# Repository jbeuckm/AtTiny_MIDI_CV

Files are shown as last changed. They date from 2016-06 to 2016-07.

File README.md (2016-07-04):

# AtTiny85 MIDI-2-CV

Here is a little MIDI interface with a few, inexpensive parts on a single-sided PCB for DIY enthusiasts. 

An ATTINY85 microcontroller ($1.67) implements the SoftwareSerial and MIDI libraries, along with one to control a MCP4822 DAC for pitch and velocity CV outputs. A simple transistor switch enables a full-swing gate output. Pitch Bend messages smoothly change the pitch independent of the gate signal.

### Pitch + CV Normals

The gate jack is normalled to the gate bus of the Eurorack connector. The pitch jack is normalled to the CV bus of the Eurorack connector.

### Set MIDI Channel

A six-byte System Exclusive message can be used to change the channel of the interface.

`F0` sysex start

`77 00 00` manufacturer + model + device

`03` channel (0 for omni) 

`F7` end of message

### Tuning

A trim pot is used to tune the pitch output for 1V/octave. At powerup, before any MIDI mesages are received, the pitch CV should be set to 8.0V.

### Assembly Notes

The MCP4822 library has been modified to sendSPIClock() using `delayMicroseconds()` instead of `delay()` so that pitch bend is smooth.

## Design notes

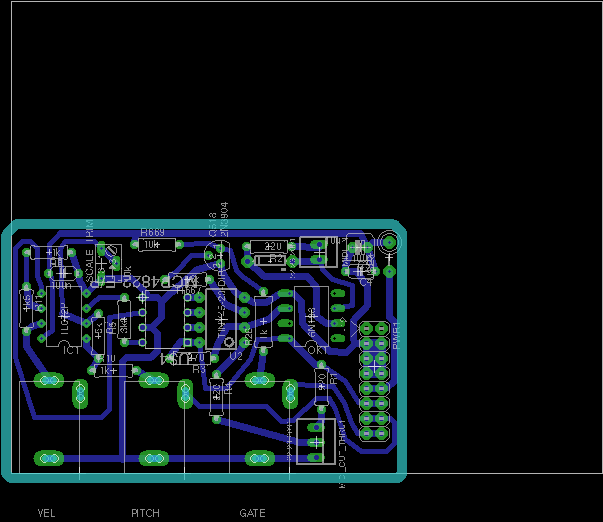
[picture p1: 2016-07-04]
eagle/attiny_midi_cv.png

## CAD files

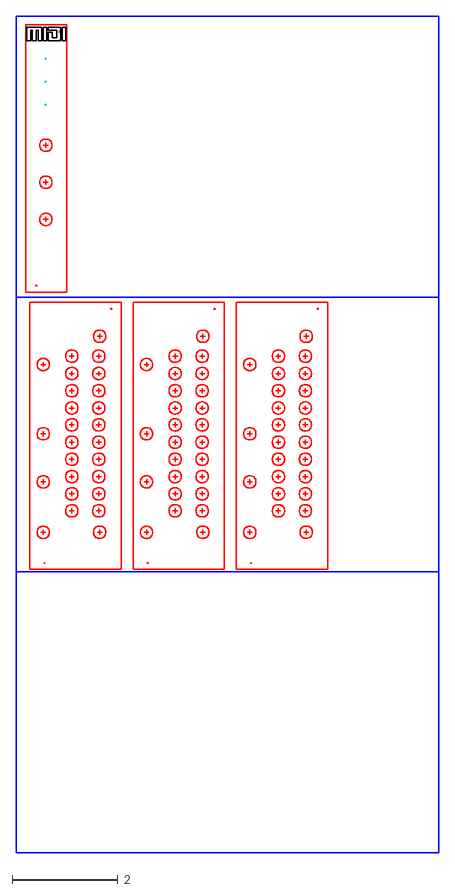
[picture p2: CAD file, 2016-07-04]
panel/attiny_midi_cv_panel.dxf
8.00 x 15.8

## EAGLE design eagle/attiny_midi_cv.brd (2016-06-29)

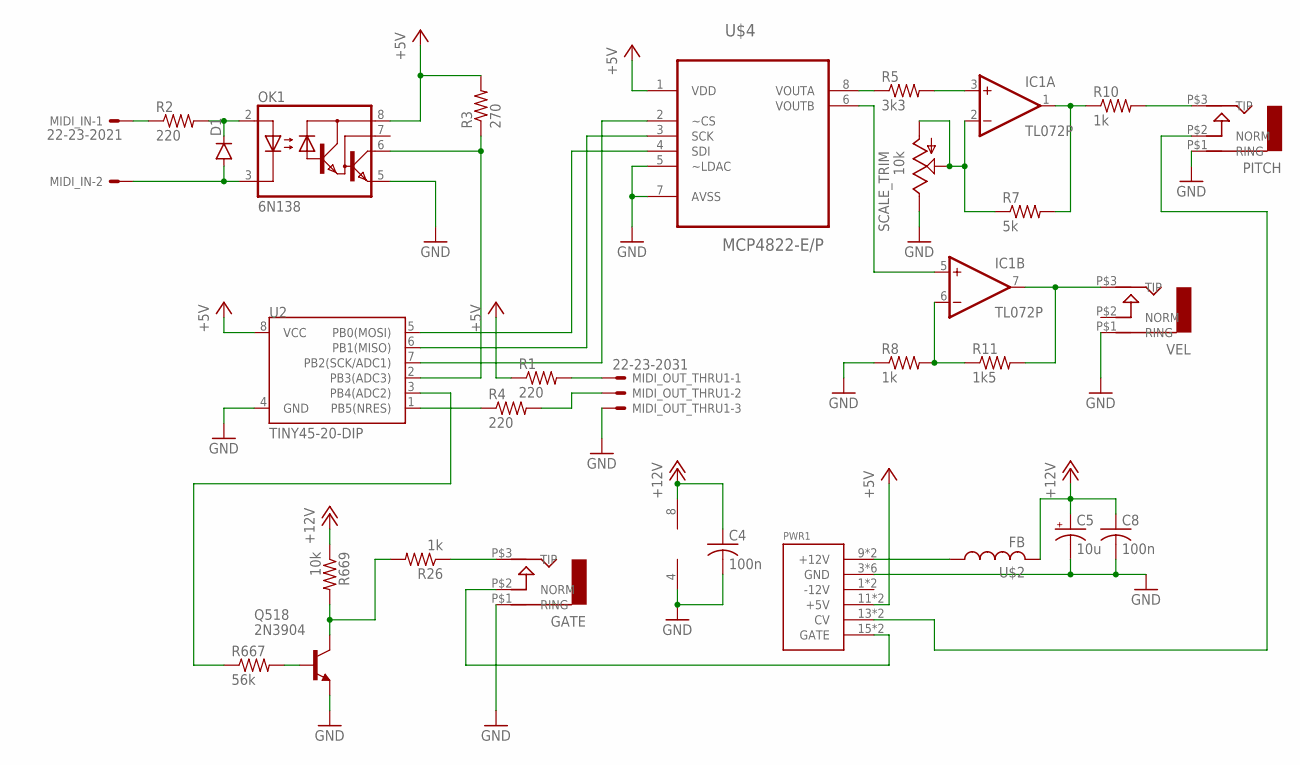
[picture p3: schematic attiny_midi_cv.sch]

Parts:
C4, C8: 100n; C050-024X044
C5: 10u; B45181A
D1: DIODE1N4148; DIODE-1N4148
GATE: AUDIO-JACK; ERTHENVAR-JACK-90DEG
IC1: TL072P; DIL08
MIDI_IN: 22-23-2021
MIDI_OUT_THRU1: 22-23-2031
OK1: 6N138; DIL08
PITCH: AUDIO-JACK; ERTHENVAR-JACK-90DEG
PWR1: POWER; POWER_16
Q518: 2N3904; TO92
R1, R2, R4: 220; 0207/7
R3: 270; 0207/7
R5: 3k3; 0207/7
R7: 5k; 0207/7
R8, R10: 1k; 0207/7
R11: 1k5; 0207/7
R26: 1k; 0309/10
R667: 56k; 0207/7
R669: 10k; 0207/7
SCALE_TRIM: 10k; B64W
U2: TINY45-20-DIP; DIP08
U$2: FB
U$4: MCP4822-E/P; DIP254P762X432-8
VEL: AUDIO-JACK; ERTHENVAR-JACK-90DEG

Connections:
+5V: OK1.8 (VCC), PWR1.11 (+5V), PWR1.12 (+5V), R1.1, R3.2, U2.8 (VCC), U$4.1 (VDD)
+12V: C4.1, C5.+, C8.1, IC1.8 (V+), R669.1, U$2.P$2 (2)
GND: C4.2, C5.-, C8.2, GATE.P$1 (RING), IC1.4 (V-), MIDI_OUT_THRU1.3, OK1.5 (GND), PITCH.P$1 (RING), PWR1.3 (GND), PWR1.4 (GND), PWR1.5 (GND), PWR1.6 (GND), PWR1.7 (GND), PWR1.8 (GND), Q518.3 (E), R8.1, SCALE_TRIM.E, U2.4 (GND), U$4.5 (~LDAC), U$4.7 (AVSS), VEL.P$1 (RING)
unnamed: R5.1, U$4.8 (VOUTA)
unnamed: D1.A, MIDI_IN.2, OK1.3 (C)
unnamed: GATE.P$3 (TIP), R26.1
unnamed: PITCH.P$3 (TIP), R10.2
unnamed: IC1.3 (+IN), R5.2
unnamed: D1.C, OK1.2 (A), R2.2
unnamed: MIDI_IN.1, R2.1
unnamed: MIDI_OUT_THRU1.1, R1.2
unnamed: MIDI_OUT_THRU1.2, R4.2
unnamed: PWR1.9 (+12V), PWR1.10 (+12V), U$2.P$1 (1)
unnamed: IC1.2 (-IN), R7.1, SCALE_TRIM.A, SCALE_TRIM.S
unnamed: IC1.6 (-IN), R8.2, R11.1
unnamed: IC1.5 (+IN), U$4.6 (VOUTB)
unnamed: PITCH.P$2 (NORM), PWR1.13 (CV), PWR1.14 (CV)
unnamed: R4.1, U2.1 (PB5(NRES))
unnamed: IC1.7 (OUT), R11.2, VEL.P$3 (TIP)
unnamed: Q518.1 (C), R26.2, R669.2
unnamed: Q518.2 (B), R667.2
unnamed: R667.1, U2.3 (PB4(ADC2))
unnamed: U2.6 (PB1(MISO)), U$4.3 (SCK)
unnamed: U2.5 (PB0(MOSI)), U$4.4 (SDI)
unnamed: IC1.1 (OUT), R7.2, R10.1
unnamed: OK1.6 (VO), R3.1, U2.2 (PB3(ADC3))
unnamed: GATE.P$2 (NORM), PWR1.15 (GATE), PWR1.16 (GATE)
unnamed: U2.7 (PB2(SCK/ADC1)), U$4.2 (~CS)

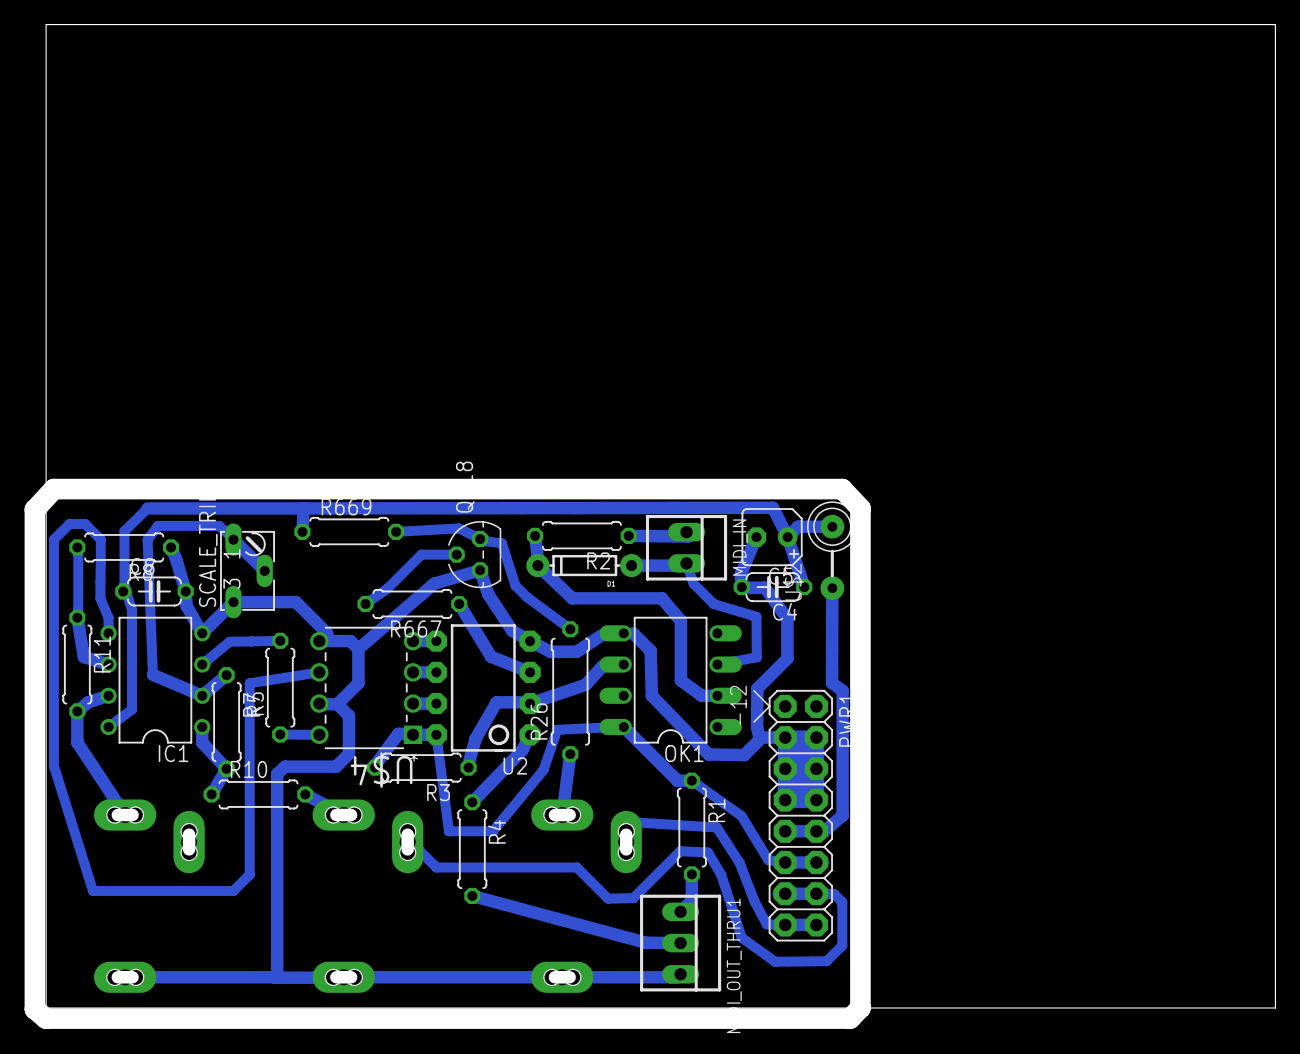
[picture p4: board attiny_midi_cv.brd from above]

Board: 2 copper layers, 100.9 x 80.9 mm, 29 parts (0 on the bottom side), 28 nets.

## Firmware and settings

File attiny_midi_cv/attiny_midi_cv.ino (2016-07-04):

#include <EEPROM.h>
#include <SoftwareSerial.h>
#include <MIDI.h>
#include "AH_MCP4922.h"

#define ALL_NOTES_OFF 123
#define CTRL_RESET 121

#define GATE_PIN 4
#define MIDI_CHANNEL_ADDRESS 0

SoftwareSerial mSerial(3, 5);
MIDI_CREATE_INSTANCE(SoftwareSerial, mSerial, midiIn);

// AH_MCP4922( SDI, SCK, CS, DAC, GAIN)
AH_MCP4922 AnalogOutput1(0,1,2,LOW,LOW);
AH_MCP4922 AnalogOutput2(0,1,2,HIGH,LOW);

byte selectedChannel = 3;

int liveNoteCount = 0;
int pitchbendOffset = 0;
int baseNoteFrequency;

void handleNoteOn(byte channel, byte pitch, byte velocity)
{
  liveNoteCount++;
  
  baseNoteFrequency = (pitch - 12) * 42;
  AnalogOutput1.setValue(baseNoteFrequency + pitchbendOffset);
  AnalogOutput2.setValue(velocity * 32);

  digitalWrite(GATE_PIN, LOW);
 }

void handleNoteOff(byte channel, byte pitch, byte velocity)
{
  liveNoteCount--;
  
  if (liveNoteCount <= 0) {
    digitalWrite(GATE_PIN, HIGH);
  }
}

void handlePitchBend(byte channel, int bend)
{
  pitchbendOffset = bend >> 4;
  AnalogOutput1.setValue(baseNoteFrequency + pitchbendOffset);
}


void playScale(int numNotes) {

  int note = 60;

  for (int i=0; i<numNotes; i++) {

      handleNoteOn(selectedChannel, note, 100);
      delay(100);
      handleNoteOff(selectedChannel, note, 100);
      delay(100);
      note++;
  }

}


void handleSystemExclusive(byte *message, unsigned size) {

  if (message[1] == 0x77) // manufacturer ID
  if (message[2] == 0)    // model ID
  if (message[3] == 0) {  // device ID
    selectedChannel = message[4] % 17;
    EEPROM.write(MIDI_CHANNEL_ADDRESS, selectedChannel);
    midiIn.begin(selectedChannel);
    
    playScale(selectedChannel);
  }
}


void handleControlChange(byte channel, byte number, byte value)
{
  switch (number) {

    case CTRL_RESET:
      handlePitchBend(selectedChannel, 0);
      break;
      
    case ALL_NOTES_OFF:
      liveNoteCount = 0;
      digitalWrite(GATE_PIN, HIGH);
      break;
  }   
}

void setup() {
  OSCCAL += 4;

  pinMode(GATE_PIN, OUTPUT);
  digitalWrite(GATE_PIN, HIGH);

  selectedChannel = EEPROM.read(MIDI_CHANNEL_ADDRESS);
  if (selectedChannel > 16) {
    selectedChannel = 0;
    EEPROM.write(MIDI_CHANNEL_ADDRESS, selectedChannel);
  }

  midiIn.setHandleNoteOn(handleNoteOn);
  midiIn.setHandleNoteOff(handleNoteOff);
  midiIn.setHandlePitchBend(handlePitchBend);
  midiIn.setHandleSystemExclusive(handleSystemExclusive);
  midiIn.setHandleControlChange(handleControlChange);
  
  midiIn.begin(selectedChannel);
}

void loop() {
  midiIn.read();  
}

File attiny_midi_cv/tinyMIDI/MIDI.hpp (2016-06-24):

/*!
 *  @file       MIDI.hpp
 *  Project     Arduino MIDI Library
 *  @brief      MIDI Library for the Arduino - Inline implementations
 *  @version    4.2
 *  @author     Francois Best
 *  @date       24/02/11
 *  @license    GPL v3.0 - Copyright Forty Seven Effects 2014
 *
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
 *  You should have received a copy of the GNU General Public License
 *  along with this program.  If not, see <http://www.gnu.org/licenses/>.
 */

#pragma once

BEGIN_MIDI_NAMESPACE

/// \brief Constructor for MidiInterface.
template<class SerialPort, class Settings>
inline MidiInterface<SerialPort, Settings>::MidiInterface(SerialPort& inSerial)
    : mSerial(inSerial)
{
    mNoteOffCallback                = 0;
    mNoteOnCallback                 = 0;
    mAfterTouchPolyCallback         = 0;
    mControlChangeCallback          = 0;
    mProgramChangeCallback          = 0;
    mAfterTouchChannelCallback      = 0;
    mPitchBendCallback              = 0;
    mSystemExclusiveCallback        = 0;
    mTimeCodeQuarterFrameCallback   = 0;
    mSongPositionCallback           = 0;
    mSongSelectCallback             = 0;
    mTuneRequestCallback            = 0;
    mClockCallback                  = 0;
    mStartCallback                  = 0;
    mContinueCallback               = 0;
    mStopCallback                   = 0;
    mActiveSensingCallback          = 0;
    mSystemResetCallback            = 0;
}

/*! \brief Destructor for MidiInterface.

 This is not really useful for the Arduino, as it is never called...
 */
template<class SerialPort, class Settings>
inline MidiInterface<SerialPort, Settings>::~MidiInterface()
{
}

// -----------------------------------------------------------------------------

/*! \brief Call the begin method in the setup() function of the Arduino.

 All parameters are set to their default values:
 - Input channel set to 1 if no value is specified
 - Full thru mirroring
 */
template<class SerialPort, class Settings>
void MidiInterface<SerialPort, Settings>::begin(Channel inChannel)
{
    // Initialise the Serial port
#if defined(FSE_AVR)
    mSerial. template open<Settings::BaudRate>();
#else
    mSerial.begin(Settings::BaudRate);
#endif

    mInputChannel = inChannel;
    mRunningStatus_TX = InvalidType;
    mRunningStatus_RX = InvalidType;

    mPendingMessageIndex = 0;
    mPendingMessageExpectedLenght = 0;

    mMessage.valid   = false;
    mMessage.type    = InvalidType;
    mMessage.channel = 0;
    mMessage.data1   = 0;
    mMessage.data2   = 0;

    mThruFilterMode = Full;
    mThruActivated  = true;
}

// -----------------------------------------------------------------------------
//                                 Output
// -----------------------------------------------------------------------------

/*! \addtogroup output
 @{
 */

/*! \brief Generate and send a MIDI message from the values given.
 \param inType    The message type (see type defines for reference)
 \param inData1   The first data byte.
 \param inData2   The second data byte (if the message contains only 1 data byte,
 set this one to 0).
 \param inChannel The output channel on which the message will be sent
 (values from 1 to 16). Note: you cannot send to OMNI.

 This is an internal method, use it only if you need to send raw data
 from your code, at your own risks.
 *
template<class SerialPort, class Settings>
void MidiInterface<SerialPort, Settings>::send(MidiType inType,
                                               DataByte inData1,
                                               DataByte inData2,
                                               Channel inChannel)
{
    // Then test if channel is valid
    if (inChannel >= MIDI_CHANNEL_OFF  ||
        inChannel == MIDI_CHANNEL_OMNI ||
        inType < 0x80)
    {
        if (Settings::UseRunningStatus)
        {
            mRunningStatus_TX = InvalidType;
        }
        return; // Don't send anything
    }

    if (inType <= PitchBend)  // Channel messages
    {
        // Protection: remove MSBs on data
        inData1 &= 0x7f;
        inData2 &= 0x7f;

        const StatusByte status = getStatus(inType, inChannel);

        if (Settings::UseRunningStatus)
        {
            if (mRunningStatus_TX != status)
            {
                // New message, memorise and send header
                mRunningStatus_TX = status;
                mSerial.write(mRunningStatus_TX);
            }
        }
        else
        {
            // Don't care about running status, send the status byte.
            mSerial.write(status);
        }

        // Then send data
        mSerial.write(inData1);
        if (inType != ProgramChange && inType != AfterTouchChannel)
        {
            mSerial.write(inData2);
        }
    }
    else if (inType >= TuneRequest && inType <= SystemReset)
    {
        sendRealTime(inType); // System Real-time and 1 byte.
    }
}

// -----------------------------------------------------------------------------

/*! \brief Send a Note On message
 \param inNoteNumber  Pitch value in the MIDI format (0 to 127).
 \param inVelocity    Note attack velocity (0 to 127). A NoteOn with 0 velocity
 is considered as a NoteOff.
 \param inChannel     The channel on which the message will be sent (1 to 16).

 Take a look at the values, names and frequencies of notes here:
 http://www.phys.unsw.edu.au/jw/notes.html
 *
template<class SerialPort, class Settings>
void MidiInterface<SerialPort, Settings>::sendNoteOn(DataByte inNoteNumber,
                                                     DataByte inVelocity,
                                                     Channel inChannel)
{
    send(NoteOn, inNoteNumber, inVelocity, inChannel);
}

/*! \brief Send a Note Off message
 \param inNoteNumber  Pitch value in the MIDI format (0 to 127).
 \param inVelocity    Release velocity (0 to 127).
 \param inChannel     The channel on which the message will be sent (1 to 16).

 Note: you can send NoteOn with zero velocity to make a NoteOff, this is based
 on the Running Status principle, to avoid sending status messages and thus
 sending only NoteOn data. sendNoteOff will always send a real NoteOff message.
 Take a look at the values, names and frequencies of notes here:
 http://www.phys.unsw.edu.au/jw/notes.html
 *
template<class SerialPort, class Settings>
void MidiInterface<SerialPort, Settings>::sendNoteOff(DataByte inNoteNumber,
                                                      DataByte inVelocity,
                                                      Channel inChannel)
{
    send(NoteOff, inNoteNumber, inVelocity, inChannel);
}
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

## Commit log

2016-06-25 fixed overlap in gnd route
    [attiny_midi_cv.brd]
2016-06-26 almost tinymidi
    [attiny_midi_cv.brd, attiny_midi_cv.sch]
2016-06-27 filtering notes by channel
2016-06-27 fixed brd and getting channel from eeprom
    [attiny_midi_cv.brd, attiny_midi_cv.sch]
2016-06-27 widened a trace
    [attiny_midi_cv.brd]
2016-06-29 schematic has thru and back to softwareserial
    [attiny_midi_cv.brd, attiny_midi_cv.sch]
2016-06-30 new gcode and osccal fix for midi in
    [attiny_midi_cv.ino]
2016-07-02 all notes off and reset controllers
    [attiny_midi_cv.ino]
2016-07-04 added a panel
    [attiny_midi_cv_panel.dxf]

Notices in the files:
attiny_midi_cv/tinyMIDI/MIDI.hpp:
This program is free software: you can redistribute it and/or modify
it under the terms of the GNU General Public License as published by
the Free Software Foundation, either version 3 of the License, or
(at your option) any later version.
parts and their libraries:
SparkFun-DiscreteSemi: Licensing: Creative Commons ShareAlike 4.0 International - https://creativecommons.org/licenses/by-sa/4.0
